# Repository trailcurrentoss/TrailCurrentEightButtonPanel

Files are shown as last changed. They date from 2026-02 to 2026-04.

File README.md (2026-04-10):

# TrailCurrent Tapper

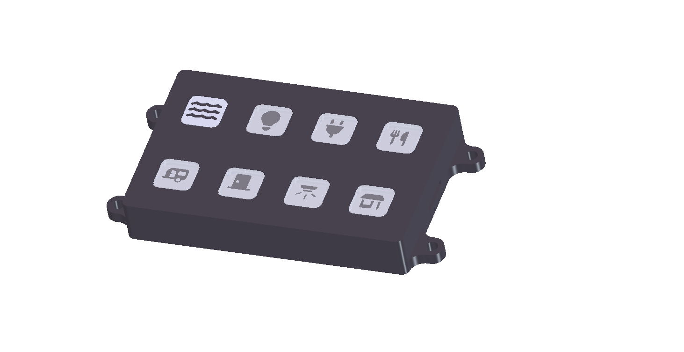
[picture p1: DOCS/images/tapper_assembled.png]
TrailCurrent Tapper


Eight-button control panel that sends toggle commands over a CAN bus interface with OTA firmware update capability. Supports targeting Torrent (PWM lighting) or Switchback (relay) modules via build-time configuration. Part of the [TrailCurrent](https://trailcurrent.com) open-source vehicle platform.

## Hardware Overview

- **Microcontroller:** ESP32 (WROOM32)
- **Function:** Physical button panel for CAN bus device control
- **Key Features:**
  - 8 momentary buttons with LED backlights
  - Button press: toggle device on/off
  - Build-time target device selection (Torrent or Switchback, instance 0-2)
  - CAN bus communication at 500 kbps
  - Over-the-air (OTA) firmware updates via WiFi
  - mDNS-based network discovery
  - LED state feedback from CAN bus
  - FreeCAD enclosure design

## Hardware Requirements

### Components

- **Microcontroller:** ESP32 development board
- **CAN Transceiver:** Vehicle CAN bus interface (TX: GPIO 15, RX: GPIO 13)

### Pin Connections

**Buttons (INPUT_PULLUP):**

| GPIO | Function |
|---|---|
| 34 | Button 1 |
| 25 | Button 2 |
| 27 | Button 3 |
| 12 | Button 4 |
| 16 | Button 5 |
| 22 | Button 6 |
| 21 | Button 7 |
| 18 | Button 8 |

**LED Backlights (OUTPUT):**

| GPIO | Function |
|---|---|
| 32 | LED 1 |
| 33 | LED 2 |
| 26 | LED 3 |
| 14 | LED 4 |
| 4 | LED 5 |
| 23 | LED 6 |
| 19 | LED 7 |
| 17 | LED 8 |

### KiCAD Library Dependencies

This project uses the consolidated [TrailCurrentKiCADLibraries](https://github.com/trailcurrentoss/TrailCurrentKiCADLibraries).

**Setup:**

```bash
# Clone the library
git clone git@github.com:trailcurrentoss/TrailCurrentKiCADLibraries.git

# Set environment variables (add to ~/.bashrc or ~/.zshrc)
export TRAILCURRENT_SYMBOL_DIR="/path/to/TrailCurrentKiCADLibraries/symbols"
export TRAILCURRENT_FOOTPRINT_DIR="/path/to/TrailCurrentKiCADLibraries/footprints"
export TRAILCURRENT_3DMODEL_DIR="/path/to/TrailCurrentKiCADLibraries/3d_models"
```

See [KICAD_ENVIRONMENT_SETUP.md](https://github.com/trailcurrentoss/TrailCurrentKiCADLibraries/blob/main/KICAD_ENVIRONMENT_SETUP.md) in the library repository for detailed setup instructions.

## Opening the Project

1. **Set up environment variables** (see Library Dependencies above)
2. **Open KiCAD:**
   ```bash
   kicad EDA/trailcurrent-tapper.kicad_pro
   ```
3. **Verify libraries load** - All symbol and footprint libraries should resolve without errors
4. **View 3D models** - Open PCB and press `Alt+3` to view the 3D visualization

## Firmware

ESP-IDF based firmware in the `main/` directory.

**Prerequisites:**
- [ESP-IDF](https://docs.espressif.com/projects/esp-idf/en/stable/esp32/get-started/) v4.1 or later

**Build and flash:**
```bash
# Set up ESP-IDF environment
. $IDF_PATH/export.sh

# Build for Torrent instance 0 (default)
idf.py build

# Build for a specific target device and instance
idf.py build -DTARGET_DEVICE=switchback -DDEVICE_INSTANCE=2

# Flash via serial
idf.py -p /dev/ttyUSB0 flash monitor

# OTA update — always use the app-only binary, never the merged binary
curl -X POST http://esp32-XXYYZZ.local/ota --data-binary @build/tapper_torrent_addr0.bin
```

### Target Device Configuration

Each Tapper is built to target a specific device type and instance, set at compile time via CMake flags:

| Flag | Values | Default | Description |
|---|---|---|---|
| `TARGET_DEVICE` | `torrent`, `switchback` | `torrent` | Target device type |
| `DEVICE_INSTANCE` | `0`, `1`, `2` | `0` | Target device instance |

These flags determine the CAN IDs used for toggle commands and status feedback:

**Torrent (PWM lighting controller):**

| Instance | Toggle TX | Status RX | Status Format |
|---|---|---|---|
| 0 | 0x18 | 0x1B | 8 bytes (one per channel, 0-255) |
| 1 | 0x19 | 0x1C | 8 bytes |
| 2 | 0x1A | 0x1D | 8 bytes |

**Switchback (relay module):**

| Instance | Toggle TX | Status RX | Status Format |
|---|---|---|---|
| 0 | 0x25 | 0x28 | 1 byte (bitmask, one bit per relay) |
| 1 | 0x26 | 0x29 | 1 byte |
| 2 | 0x27 | 0x2A | 1 byte |

When switching between device types, run `idf.py fullclean` before rebuilding to clear cached CMake variables.

Multiple Tappers can target the same device instance — there is no limit.

#### Building All Variants

Use `build-all.sh` to build all 6 firmware variants (2 targets x 3 addresses):

```bash
./build-all.sh
```

This produces two binaries per variant — one for OTA updates, one for the web flasher:

| File | Contents | Used By |
|---|---|---|
| `build/tapper_{target}_addr{N}.bin` | Application image only | Headwaters OTA (`deploy.sh`, `ota.js`), direct `curl` uploads |
| `build/tapper_{target}_addr{N}_merged.bin` | Bootloader + partition table + OTA data + application | Web flasher (full flash at 0x0) |

The two binary types exist because OTA and the web flasher write to different targets. Headwaters OTA sends the binary to the device's `/ota` HTTP endpoint, which calls `esp_ota_write` to write it to a single app partition. That function validates the image as an application — a merged binary starts with the bootloader instead of an app header, so it would fail validation. The web flasher writes the entire flash contents starting at offset 0x0, so it needs all partitions combined into one file.

#### Creating a GitHub Release

After building all variants, attach all 12 binaries (6 app-only + 6 merged) as release assets:

```bash
git tag -a v1.0.0 -m "Firmware release v1.0.0"
git push origin v1.0.0

gh release create v1.0.0 \
  build/tapper_torrent_addr0.bin \
  build/tapper_torrent_addr1.bin \
  build/tapper_torrent_addr2.bin \
  build/tapper_switchback_addr0.bin \
  build/tapper_switchback_addr1.bin \
  build/tapper_switchback_addr2.bin \
  build/tapper_torrent_addr0_merged.bin \
  build/tapper_torrent_addr1_merged.bin \
  build/tapper_torrent_addr2_merged.bin \
  build/tapper_switchback_addr0_merged.bin \
  build/tapper_switchback_addr1_merged.bin \
  build/tapper_switchback_addr2_merged.bin \
  --repo trailcurrentoss/TrailCurrentTapper \
  --title "v1.0.0" \
  --notes "Firmware release v1.0.0"
```

Both the Headwaters deployment system and the web flasher pull from GitHub releases. The web flasher matches `_merged.bin` files by name for full-flash use. The Headwaters deployment system (`fetch-firmware.sh`) downloads the app-only `tapper_{target}_addr{N}.bin` files for OTA delivery.

### CAN Bus Protocol

**Transmit (Panel to Bus):**

| CAN ID | Bytes | Description |
|---|---|---|
| Torrent: 0x18-0x1A | 1 | Button toggle (byte 0 = button index 0-7) |
| Switchback: 0x25-0x27 | 1 | Button toggle (byte 0 = button index 0-7) |

**Receive (Bus to Panel):**

| CAN ID | Bytes | Description |
|---|---|---|
| 0x00 | 3 | OTA update trigger (MAC-based device targeting) |
| 0x01 | var | WiFi credential provisioning (chunked protocol) |
| 0x02 | 0 | Discovery trigger (broadcast) |
| 0x04 | 6 | Version report on boot: `[mac3, mac4, mac5, major, minor, patch]` |
| Torrent: 0x1B-0x1D | 8 | LED state (1 byte per channel, 0=off, non-zero=on) |
| Switchback: 0x28-0x2A | 1 | LED state (bitmask, 1 bit per relay) |

### Button Behavior

- **Press**: Sends toggle command (debounced, 50ms). Byte 0 = button index (0-7).

### OTA Updates

WiFi credentials are provisioned over CAN (ID 0x01) and stored in NVS. When an OTA trigger (ID 0x00) matches this device's MAC-derived hostname, the module connects to WiFi, advertises via mDNS, and accepts firmware uploads at `POST /ota`.

### Network Discovery

On CAN trigger (ID 0x02), the module joins WiFi and advertises itself via mDNS service `_trailcurrent._tcp` with TXT records for module type, target device, CAN ID, device instance, and firmware version.

## Manufacturing

- **PCB Files:** Ready for fabrication via standard PCB services (JLCPCB, OSH Park, etc.)
- **BOM Generation:** Export BOM from KiCAD schematic (Tools > Generate BOM)
- **Enclosure:** FreeCAD design included in `CAD/` directory
- **JLCPCB Assembly:** See [BOM_ASSEMBLY_WORKFLOW.md](https://github.com/trailcurrentoss/TrailCurrentKiCADLibraries/blob/main/BOM_ASSEMBLY_WORKFLOW.md) for detailed assembly workflow

## Project Structure

```
├── CAD/                          # FreeCAD enclosure design
├── EDA/                          # KiCAD hardware design files
│   ├── trailcurrent-tapper.kicad_pro
│   ├── trailcurrent-tapper.kicad_sch
│   └── trailcurrent-tapper.kicad_pcb
├── main/                         # ESP-IDF firmware source
│   ├── main.c                    # Button handling, LED control, CAN communication
│   ├── ota.c / ota.h             # OTA updates and WiFi provisioning
│   ├── discovery.c / discovery.h # mDNS network discovery
│   ├── CMakeLists.txt            # Component build configuration
│   └── idf_component.yml         # Managed component dependencies
├── CMakeLists.txt                # ESP-IDF project root
├── sdkconfig.defaults            # Default SDK configuration
├── build-all.sh                  # Build all 6 variants (2 targets x 3 addresses)
└── partitions.csv                # ESP32 flash partition layout (dual OTA)
```

## License

MIT License - See LICENSE file for details.

## Contributing

Improvements and contributions are welcome! Please submit issues or pull requests.

## Support

For questions about:
- **KiCAD setup:** See [KICAD_ENVIRONMENT_SETUP.md](https://github.com/trailcurrentoss/TrailCurrentKiCADLibraries/blob/main/KICAD_ENVIRONMENT_SETUP.md)
- **Assembly workflow:** See [BOM_ASSEMBLY_WORKFLOW.md](https://github.com/trailcurrentoss/TrailCurrentKiCADLibraries/blob/main/BOM_ASSEMBLY_WORKFLOW.md)

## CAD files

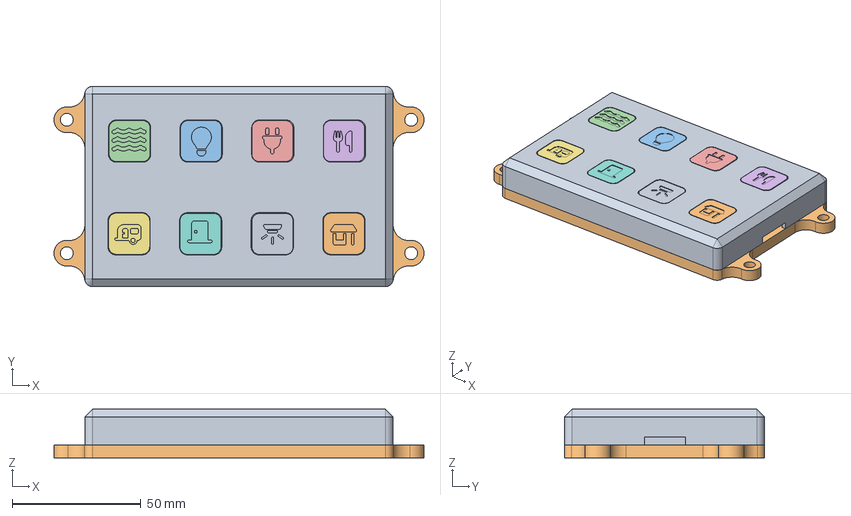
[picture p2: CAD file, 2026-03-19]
CAD/trailer-switch-panel-eight-buttons.FCStd
143.9 x 77.8 x 18.9 mm
BodyFrontMountPcbButtonCover
BodyCaseBack
BodyButtonCapBulb
BodyButtonCapWater
BodyButtonCapPower
BodyButtonCapKitchen
BodyButtonCapTrailer
BodyButtonCapEntry
BodyButtonCapUnderCabinet
BodyButtonCapPorch

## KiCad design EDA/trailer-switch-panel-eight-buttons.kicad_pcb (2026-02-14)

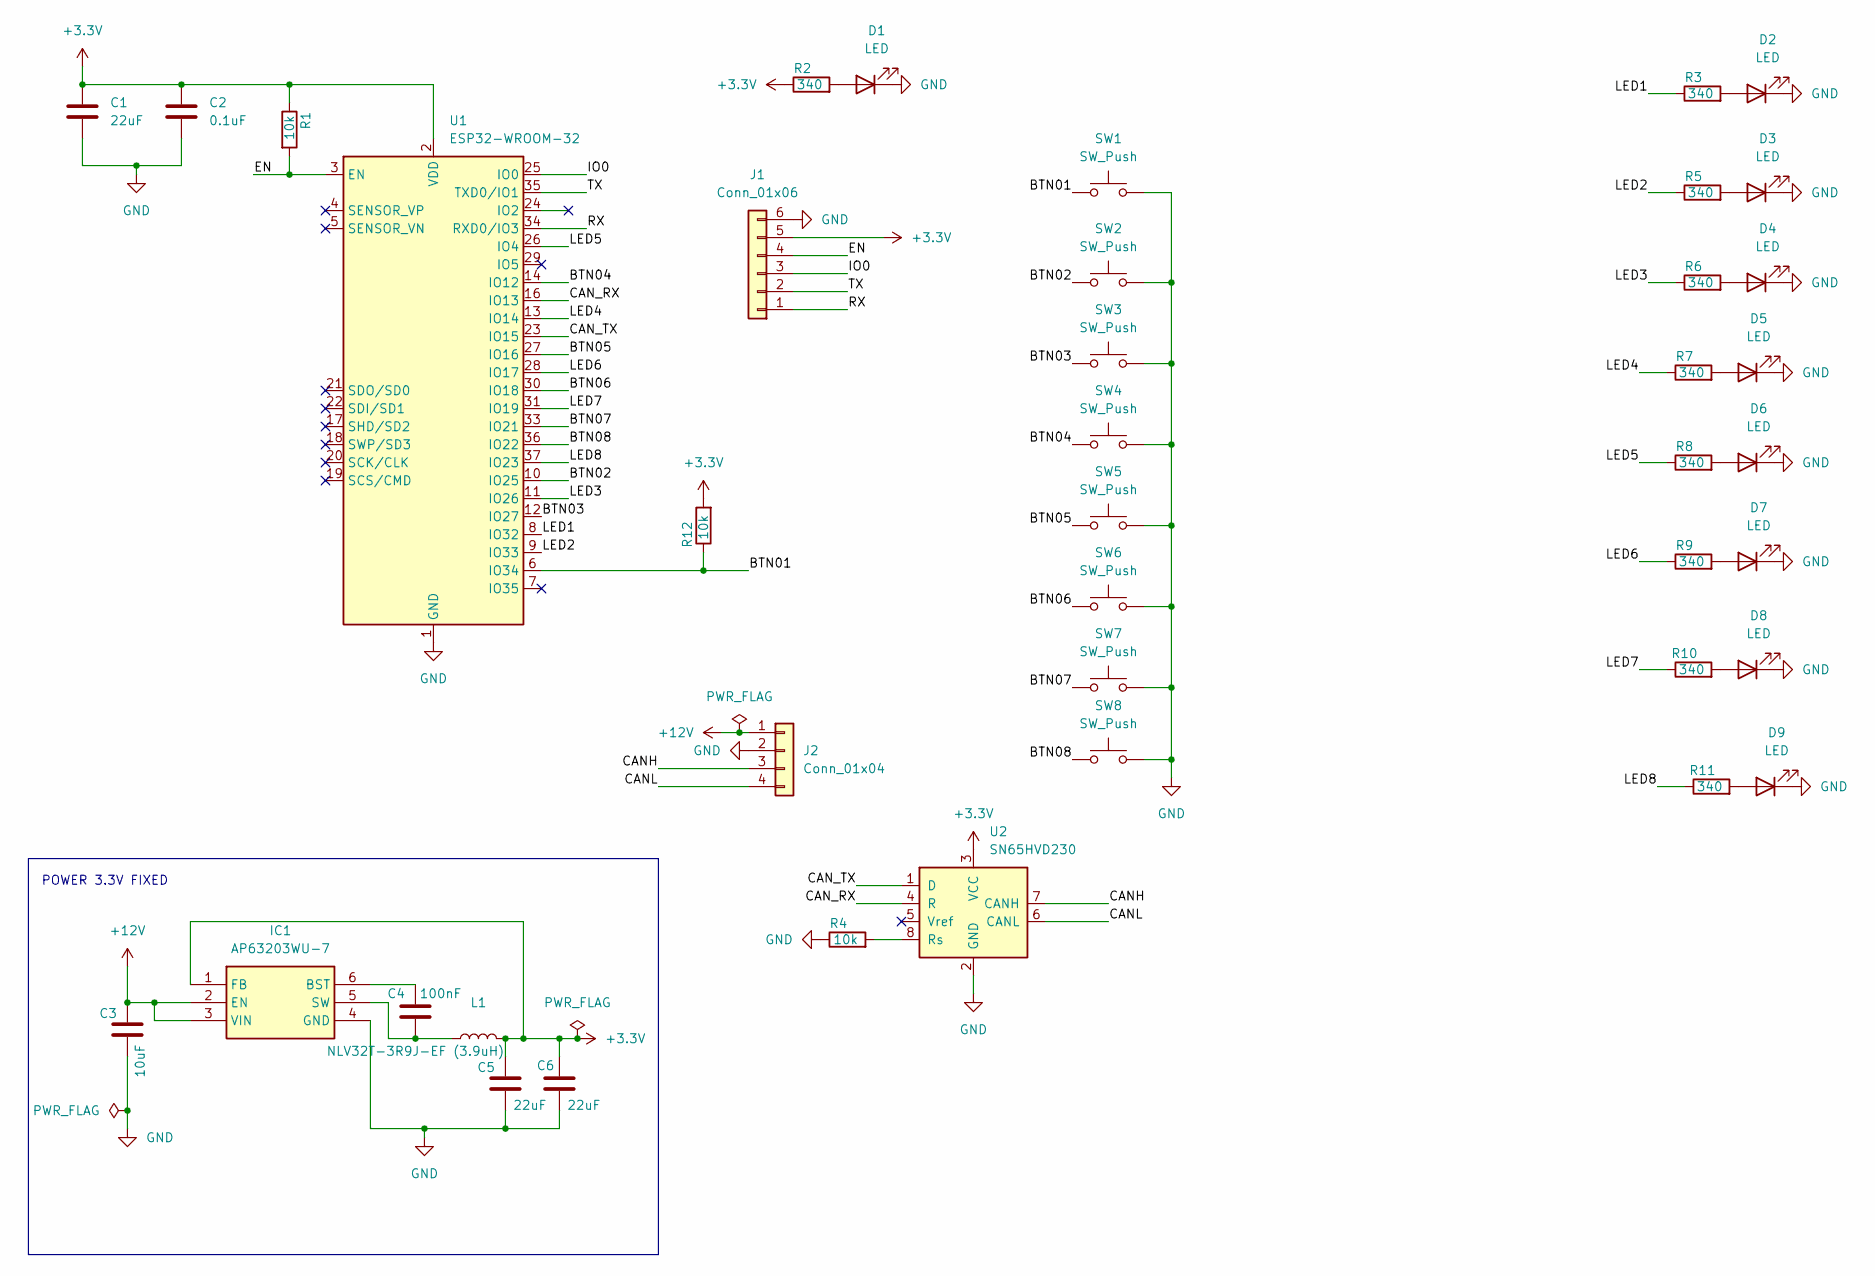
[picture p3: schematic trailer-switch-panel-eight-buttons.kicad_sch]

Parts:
C1, C5, C6: 22uF; C_1206_3216Metric_Pad1.33x1.80mm_HandSolder
C2: 0.1uF; C_1206_3216Metric_Pad1.33x1.80mm_HandSolder
C3: 10uF; C_1206_3216Metric
C4: 100nF; C_1206_3216Metric
D1, D2, D3, D4, D5, D6, D7, D8, D9: LED; LED_1206_3216Metric_Pad1.42x1.75mm_HandSolder
IC1: AP63203WU-7; AP63203WU7; Mouser Part Number 621-AP63203WU-7
J1: Conn_01x06; PinHeader_1x06_P2.54mm_Horizontal
J2: Conn_01x04; CAN_PLUS_POWER
L1: NLV32T-3R9J-EF (3.9uH); INDM3225X240N
R1, R4, R12: 10k; R_1206_3216Metric_Pad1.30x1.75mm_HandSolder
R2, R3, R5, R6, R7, R8, R9, R10, R11: 340; R_1206_3216Metric_Pad1.30x1.75mm_HandSolder
SW1, SW2, SW3, SW4, SW5, SW6, SW7, SW8: SW_Push; SW_PUSH_6mm
U1: ESP32-WROOM-32; ESP32-WROOM-32U
U2: SN65HVD230; SOIC-8_3.9x4.9mm_P1.27mm

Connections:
+3.3V: C1.1, C2.1, C5.1, C6.1, IC1.1 (FB), J1.5, L1.2, R1.1, R2.1, R12.2, U1.2 (VDD), U2.3 (VCC)
+12V: C3.1, IC1.2 (EN), IC1.3 (VIN), J2.1
/BTN01: R12.1, SW1.1, U1.6 (IO34)
/BTN02: SW2.1, U1.10 (IO25)
/BTN03: SW3.1, U1.12 (IO27)
/BTN04: SW4.1, U1.14 (IO12)
/BTN05: SW5.1, U1.27 (IO16)
/BTN06: SW6.1, U1.30 (IO18)
/BTN07: SW7.1, U1.33 (IO21)
/BTN08: SW8.1, U1.36 (IO22)
/CANH: J2.3, U2.7 (CANH)
/CANL: J2.4, U2.6 (CANL)
/CAN_RX: U1.16 (IO13), U2.4 (R)
/CAN_TX: U1.23 (IO15), U2.1 (D)
/EN: J1.4, R1.2, U1.3 (EN)
/IO0: J1.3, U1.25 (IO0)
/LED1: R3.1, U1.8 (IO32)
/LED2: R5.1, U1.9 (IO33)
/LED3: R6.1, U1.11 (IO26)
/LED4: R7.1, U1.13 (IO14)
/LED5: R8.1, U1.26 (IO4)
/LED6: R9.1, U1.28 (IO17)
/LED7: R10.1, U1.31 (IO19)
/LED8: R11.1, U1.37 (IO23)
/RX: J1.1, U1.34 (RXD0/IO3)
/TX: J1.2, U1.35 (TXD0/IO1)
GND: C1.2, C2.2, C3.2, C5.2, C6.2, D1.1 (K), D2.1 (K), D3.1 (K), D4.1 (K), D5.1 (K), D6.1 (K), D7.1 (K), D8.1 (K), D9.1 (K), IC1.4 (GND), J1.6, J2.2, R4.1, SW1.2, SW2.2, SW3.2, SW4.2, SW5.2, SW6.2, SW7.2, SW8.2, U1.1 (GND), U1.15 (GND), U1.38 (GND), U1.39 (GND), U2.2 (GND)
unnamed: D1.2 (A), R2.2
unnamed: D2.2 (A), R3.2
unnamed: D3.2 (A), R5.2
unnamed: D4.2 (A), R6.2
unnamed: D5.2 (A), R7.2
unnamed: D6.2 (A), R8.2
unnamed: D7.2 (A), R9.2
unnamed: D8.2 (A), R10.2
unnamed: D9.2 (A), R11.2
unnamed: C4.1, IC1.6 (BST)
unnamed: C4.2, IC1.5 (SW), L1.1
unnamed: R4.2, U2.8 (Rs)

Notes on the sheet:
POWER 3.3V FIXED

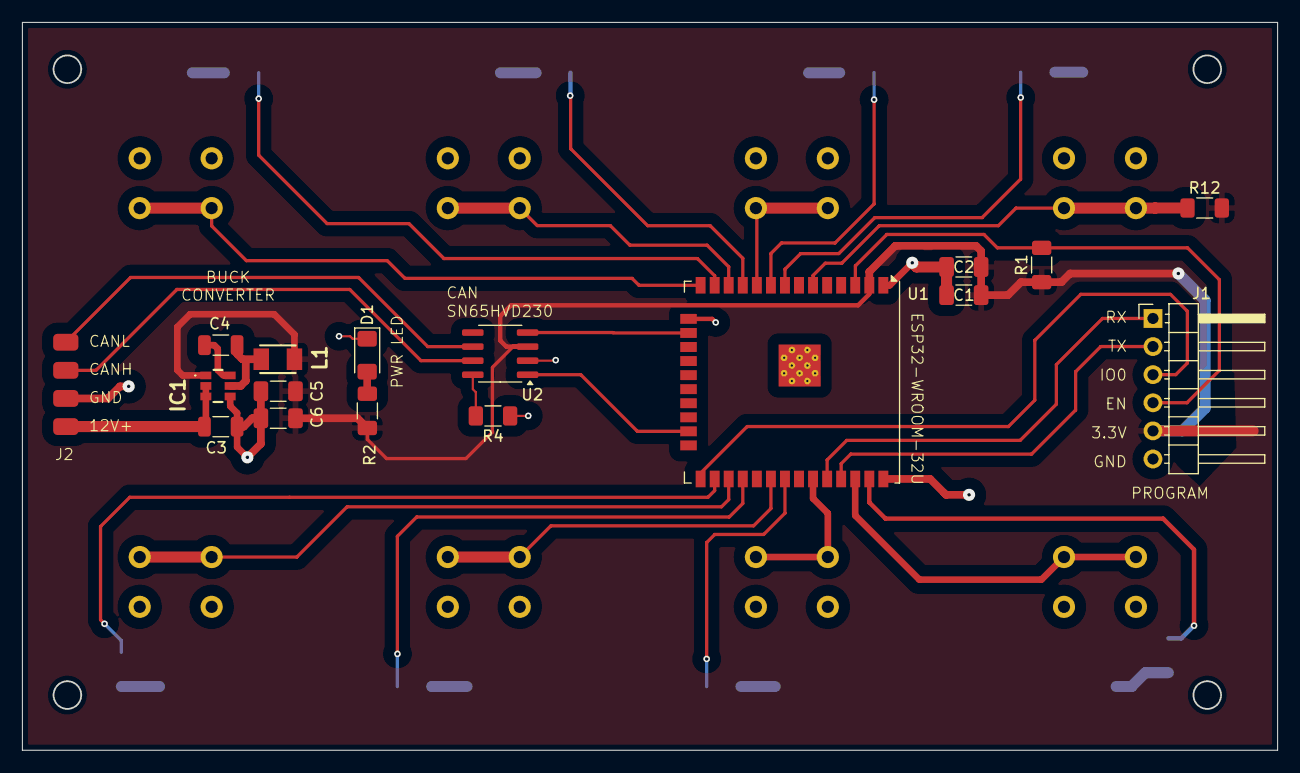
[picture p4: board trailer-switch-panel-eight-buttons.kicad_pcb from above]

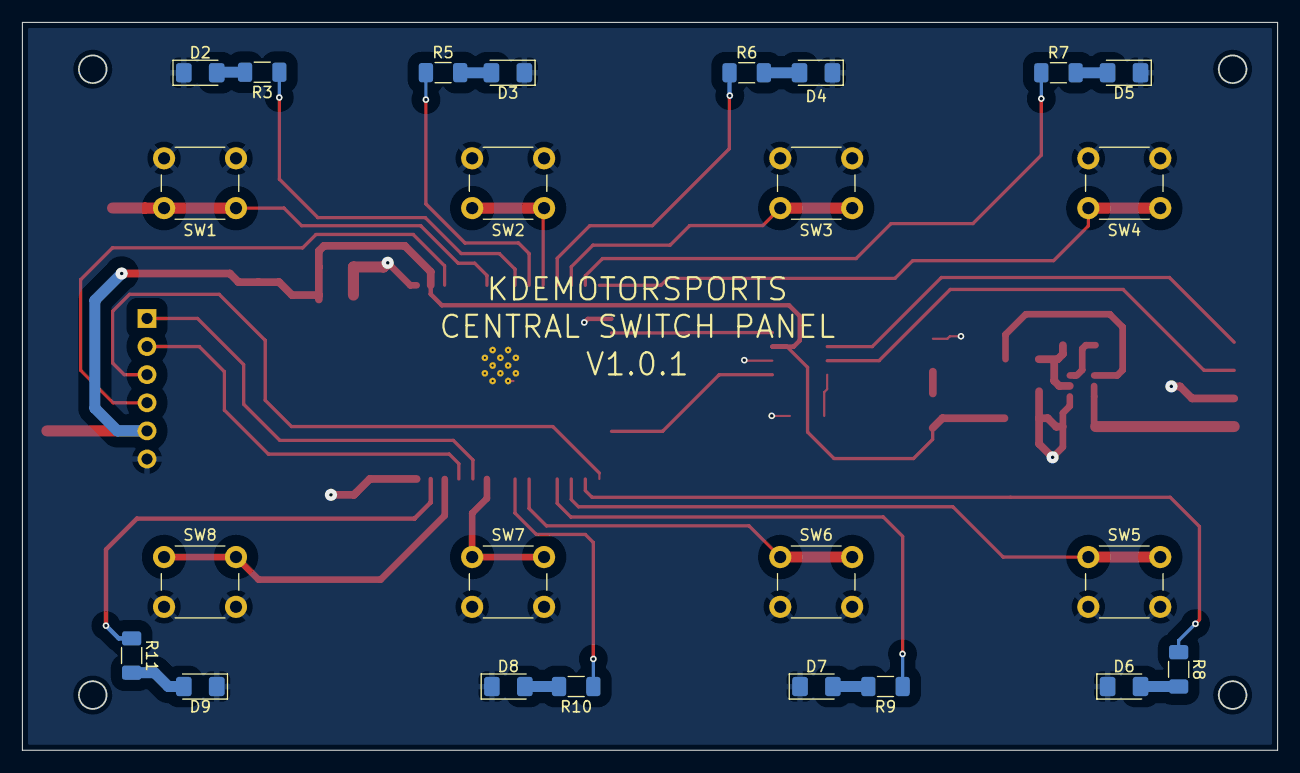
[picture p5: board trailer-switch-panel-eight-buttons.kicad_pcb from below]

Board: 2 copper layers, 113.4 x 65.8 mm, 41 parts (24 on the bottom side), 39 nets.

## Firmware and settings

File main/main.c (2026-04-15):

#include <stdio.h>
#include <string.h>
#include "freertos/FreeRTOS.h"
#include "freertos/task.h"
#include "driver/gpio.h"
#include "driver/twai.h"
#include "esp_log.h"
#include "esp_timer.h"
#include "can_common.h"
#include "board.h"
#include "wifi_config.h"
#include "ota.h"
#include "discovery.h"

static const char *TAG = "tapper";

// =============================================================================
// Pin Definitions — ESP32-WROOM-32 8-Button Control Panel
// =============================================================================

// CAN bus pins
#define CAN_TX_PIN   15
#define CAN_RX_PIN   13

// 8 button input pins (active low, internal pull-up)
static const gpio_num_t BUTTON_PINS[8] = {
    GPIO_NUM_34,  // BTN1
    GPIO_NUM_25,  // BTN2
    GPIO_NUM_27,  // BTN3
    GPIO_NUM_12,  // BTN4
    GPIO_NUM_16,  // BTN5
    GPIO_NUM_22,  // BTN6
    GPIO_NUM_21,  // BTN7
    GPIO_NUM_18,  // BTN8
};

// 8 LED backlight output pins
static const gpio_num_t LED_PINS[8] = {
    GPIO_NUM_32,  // LED1
    GPIO_NUM_33,  // LED2
    GPIO_NUM_26,  // LED3
    GPIO_NUM_14,  // LED4
    GPIO_NUM_4,   // LED5
    GPIO_NUM_23,  // LED6
    GPIO_NUM_19,  // LED7
    GPIO_NUM_17,  // LED8
};

#define NUM_BUTTONS  8

// =============================================================================
// CAN Bus Configuration
// =============================================================================

#define CAN_BAUDRATE           500000
#define TX_PROBE_INTERVAL_MS   2000

// CAN protocol IDs
#define CAN_ID_OTA              0x00
#define CAN_ID_WIFI_CONFIG      0x01
#define CAN_ID_DISCOVERY_TRIGGER 0x02

// CAN IDs computed from build flags (TARGET_DEVICE + DEVICE_INSTANCE)
#ifndef DEVICE_INSTANCE
#define DEVICE_INSTANCE 0
#endif
#if DEVICE_INSTANCE < 0 || DEVICE_INSTANCE > 2
#error "DEVICE_INSTANCE must be 0, 1, or 2"
#endif

#define CAN_ID_TOGGLE  (CAN_ID_TOGGLE_BASE + DEVICE_INSTANCE)
#define CAN_ID_STATUS  (CAN_ID_STATUS_BASE + DEVICE_INSTANCE)

// =============================================================================
// Button Timing Constants
// =============================================================================

#define DEBOUNCE_DELAY_US      (50 * 1000LL)    // 50ms debounce

// =============================================================================
// Button State
// =============================================================================

typedef struct {
    bool     pressed;
    bool     toggle_sent;
    int64_t  press_start_us;
} button_state_t;

static button_state_t s_buttons[NUM_BUTTONS] = {0};

// =============================================================================
// GPIO Initialization
// =============================================================================

static void gpio_init_all(void)
{
    // Configure LED pins as outputs, initially off
    for (int i = 0; i < NUM_BUTTONS; i++) {
        gpio_config_t led_cfg = {
            .pin_bit_mask = (1ULL << LED_PINS[i]),
            .mode         = GPIO_MODE_OUTPUT,
            .pull_up_en   = GPIO_PULLUP_DISABLE,
            .pull_down_en = GPIO_PULLDOWN_DISABLE,
            .intr_type    = GPIO_INTR_DISABLE,
        };
        gpio_config(&led_cfg);
        gpio_set_level(LED_PINS[i], 0);
    }

    // Configure button pins as inputs with pull-up
    // Note: GPIOs 34-39 are input-only and have no internal pull-up;
    // they require an external pull-up resistor on the PCB.
    for (int i = 0; i < NUM_BUTTONS; i++) {
        bool has_internal_pullup = (BUTTON_PINS[i] < GPIO_NUM_34);
        gpio_config_t btn_cfg = {
            .pin_bit_mask = (1ULL << BUTTON_PINS[i]),
            .mode         = GPIO_MODE_INPUT,
            .pull_up_en   = has_internal_pullup ? GPIO_PULLUP_ENABLE : GPIO_PULLUP_DISABLE,
            .pull_down_en = GPIO_PULLDOWN_DISABLE,
            .intr_type    = GPIO_INTR_DISABLE,
        };
        gpio_config(&btn_cfg);
    }

    ESP_LOGI(TAG, "GPIO initialized: 8 buttons (INPUT_PULLUP), 8 LEDs (OUTPUT)");
}

// =============================================================================
// CAN TX Helpers
// =============================================================================

static void send_toggle(int button_index)
{
    twai_message_t msg = {
        .identifier = CAN_ID_TOGGLE,
        .data_length_code = 1,
        .data = { button_index },
    };
    twai_transmit(&msg, 0);
    ESP_LOGI(TAG, "Button %d toggle sent (ID 0x%02X)", button_index + 1,
             CAN_ID_TOGGLE);
}

// =============================================================================
// LED State Handler (RX from target device status message)
// =============================================================================

static void handle_led_state(const uint8_t *data, uint8_t len)
{
#ifdef TARGET_DEVICE_TORRENT
    // Torrent status: 8 bytes, one per channel (PWM value 0-255)
    if (len < 8) return;
    for (int i = 0; i < NUM_BUTTONS; i++) {
        gpio_set_level(LED_PINS[i], data[i] > 0 ? 1 : 0);
    }
#elif defined(TARGET_DEVICE_SWITCHBACK)
    // Switchback status: 1 byte bitmask, one bit per relay
    if (len < 1) return;
    uint8_t bitmask = data[0];
    for (int i = 0; i < NUM_BUTTONS; i++) {
        gpio_set_level(LED_PINS[i], (bitmask >> i) & 1);
    }
#endif
}

// =============================================================================
// Button Scanning — runs in main task at ~1ms resolution
// =============================================================================

static void button_scan(void)
{
    int64_t now_us = esp_timer_get_time();

    for (int i = 0; i < NUM_BUTTONS; i++) {
        bool pin_low = (gpio_get_level(BUTTON_PINS[i]) == 0);
        button_state_t *btn = &s_buttons[i];

        if (pin_low) {
            if (!btn->pressed) {
                btn->pressed = true;
                btn->press_start_us = now_us;
                btn->toggle_sent = false;
            } else if (!btn->toggle_sent &&
                       (now_us - btn->press_start_us) >= DEBOUNCE_DELAY_US) {
                btn->toggle_sent = true;
                send_toggle(i);
            }
        } else {
            if (btn->pressed) {
                btn->pressed = false;
                btn->toggle_sent = false;
            }
        }
    }
}

// =============================================================================
// TWAI (CAN) task — runs independently
// =============================================================================


static void twai_task(void *arg)
{
    // Configure alerts BEFORE any bus activity so no error transitions are missed.
    twai_reconfigure_alerts(CAN_COMMON_ALERTS, NULL);

    // Alerts armed — version broadcast TX failure is caught by the state machine.
    can_common_version_broadcast();

    typedef enum { TX_ACTIVE, TX_PROBING } tx_state_t;
    bool bus_off = false;
    tx_state_t tx_state = TX_ACTIVE;
    int tx_fail_count = 0;
    const int TX_FAIL_THRESHOLD = 3;

    while (1) {
        uint32_t triggered;
        twai_read_alerts(&triggered, pdMS_TO_TICKS(10));

        // --- Bus error handling ---
        if (triggered & TWAI_ALERT_BUS_OFF) {
            ESP_LOGE(TAG, "TWAI bus-off, initiating recovery");
            bus_off = true;
            twai_initiate_recovery();
            // No continue — fall through so RX_DATA in the same poll is still processed.
        }
        if (triggered & TWAI_ALERT_BUS_RECOVERED) {
            ESP_LOGI(TAG, "TWAI bus recovered, restarting");
            twai_start();
            bus_off = false;
            tx_fail_count = 0;
            tx_state = TX_PROBING;
        }
        if (triggered & TWAI_ALERT_ERR_PASS) {
            ESP_LOGW(TAG, "TWAI error passive (no peers ACKing?)");
        }
        if (triggered & TWAI_ALERT_TX_FAILED) {
            if (tx_state == TX_ACTIVE) {
                tx_fail_count++;
                if (tx_fail_count >= TX_FAIL_THRESHOLD) {
                    tx_state = TX_PROBING;
                    ESP_LOGW(TAG, "TWAI no peers detected, entering slow probe");
                }
            }
        }
        if (triggered & TWAI_ALERT_TX_SUCCESS) {
            if (tx_state == TX_PROBING) {
                tx_state = TX_ACTIVE;
                tx_fail_count = 0;
                can_common_version_broadcast();
                ESP_LOGI(TAG, "TWAI probe ACK'd, peer detected, resuming normal TX");
            }
            tx_fail_count = 0;
        }

        // --- Drain received messages ---
        if (triggered & TWAI_ALERT_RX_DATA) {
            if (tx_state == TX_PROBING) {
                tx_state = TX_ACTIVE;
                tx_fail_count = 0;
                can_common_version_broadcast();
                ESP_LOGI(TAG, "TWAI peer detected via RX, resuming normal TX");
            }
            twai_message_t msg;
            while (twai_receive(&msg, 0) == ESP_OK) {
                if (msg.rtr) continue;

                if (msg.identifier == CAN_ID_OTA) {
                    ota_handle_trigger(msg.data, msg.data_length_code);
                } else if (msg.identifier == CAN_ID_WIFI_CONFIG) {
                    wifi_config_handle_can(msg.data, msg.data_length_code);
                } else if (msg.identifier == CAN_ID_DISCOVERY_TRIGGER) {
                    discovery_handle_trigger();
                } else if (msg.identifier == CAN_ID_STATUS) {
                    handle_led_state(msg.data, msg.data_length_code);
                }
            }
        }

        // Tapper is input-only — no periodic status TX.
        // Button presses are sent from the main task via send_toggle.
        (void)bus_off;
    }
}

// =============================================================================
// Device Configuration Accessors (compile-time from build flags)
// =============================================================================

uint8_t tapper_get_device_instance(void) { return DEVICE_INSTANCE; }
const char *tapper_get_target_device(void) { return TARGET_DEVICE_NAME; }
uint32_t tapper_get_toggle_id(void) { return CAN_ID_TOGGLE; }
uint32_t tapper_get_status_id(void) { return CAN_ID_STATUS; }

// =============================================================================
// Main application
// =============================================================================

void app_main(void)
{
    ESP_LOGI(TAG, "=== TrailCurrent Tapper ===");
    ESP_LOGI(TAG, "8-Button Control Panel with CAN Bus");

    // Initialize NVS and load WiFi credentials
    ESP_ERROR_CHECK(wifi_config_init());

    char ssid[33] = {0};
    char password[64] = {0};
    if (wifi_config_load(ssid, sizeof(ssid), password, sizeof(password))) {
        ESP_LOGI(TAG, "WiFi credentials loaded from NVS");
    } else {
        ESP_LOGI(TAG, "No WiFi credentials — OTA disabled until provisioned via CAN");
    }

    // Initialize discovery and OTA (must be after wifi_config_init)
    discovery_init();
    ota_init();

    ESP_LOGI(TAG, "Hostname: %s", wifi_config_get_hostname());
    ESP_LOGI(TAG, "Target: %s instance %d (toggle=0x%02X, status=0x%02X)",
             TARGET_DEVICE_NAME, DEVICE_INSTANCE, CAN_ID_TOGGLE, CAN_ID_STATUS);

    // Initialize GPIO for buttons and LEDs
    gpio_init_all();

    // CAN runs in its own task so bus errors never block button scanning
    ESP_ERROR_CHECK(can_common_init(CAN_TX_PIN, CAN_RX_PIN));
    xTaskCreatePinnedToCore(twai_task, "twai", 4096, NULL, 5, NULL, 1);

    ESP_LOGI(TAG, "Setup complete");

    // Main task scans buttons at ~10ms resolution
    while (1) {
        button_scan();
        vTaskDelay(pdMS_TO_TICKS(10));
    }
}

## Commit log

2026-02-14 Starting project
    [partitions.csv, trailer-switch-panel-eight-buttons.FCStd, trailer-switch-panel-eight-buttons.kicad_pcb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]
2026-03-15 Fixing to NO_ACK so modules can come onto and leave the can bus without disruption
2026-03-19 Added image of assembled case to readme
    [trailer-switch-panel-eight-buttons.FCStd]
2026-03-27 Moved to ESP-IDF and adjusted brightness scaling.
    [partitions.csv]
2026-03-28 Removing brightness in prep for tapper being able to flash to different IDs and also to control switchback
2026-03-28 Updated to allow tapper to be configured to different Torrent devices
2026-03-28 Add build flags to allow pairing of tapper to Torrent or Switchback devices
2026-03-28 Fixing issue with CAN Bus stops responding when discovery happens
    [main.c]
